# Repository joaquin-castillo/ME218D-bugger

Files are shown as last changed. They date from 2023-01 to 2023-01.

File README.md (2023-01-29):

# ME218D-bugger
Design files and documentation for the ME 218 D-bugger. The D-bugger is a tool for ME 218 student students to monitor and visualize the Events and Services Framework.

## PCBA fabrication and assembly
### Fab House
We had [JLCPCB](https://jlcpcb.com/) fabricate the boards and assemble the bottom sides. We elected to solder the top sides ourselves because, in addition to the three thru-hole components, there are only four 1206 SMD components on the top sides, and having both sides assembled with have cost significantly more. 1206 SMD packages are not difficult to solder by hand with the right equipment. If you are new to SMD soldering, see this [Intro to Soldering](https://sites.google.com/stanford.edu/soldering-internal/learning?authuser=0) tutorial page to learn the basics and best practices of hand soldering. A lesson we learned was to avoid no-clean solder flux and opt for water-soluble solder flux instead. This can be cleaned with isopropyl alcohol (at least 90%) or water and will not leave the board sticky and goopy after soldering.

The fabrication files needed to place an order with JLC are listed below:
- *Intermediary_revC_fab_20221219.zip*
- *Intermediary_revC_jlc_bottom.csv*
- *Intermediary_revC_4layer-bottom-pos.csv*

If for any reason you need to regenerate the fab files, JLC has some tutorials on [How to generate Gerber and Drill files](https://support.jlcpcb.com/article/194-how-to-generate-gerber-and-drill-files-in-kicad-6) and [How to generate the BOM and Centroid file](https://support.jlcpcb.com/article/84-how-to-generate-the-bom-and-centroid-file-from-kicad) specifically for KiCAD. The BOM and centroid file (aka pick and place file) are used for component assembly. In our experience, getting the centroid file in the right position and orientation relative to the board preview in JLC's quoting tool was a little finicky. This doesn't have to be perfect as JLC will have an engineer look at your files and correct anything before you approve the order. Something else to note is that for assembly, JLC requires some non-plated tooling hole to be added to the board for their processes. These have already been added to the design, but in case you want to see their requirements, that can be found on this page: [How to add tooling holes for PCB assembly order](https://support.jlcpcb.com/article/92-how-to-add-tooling-holes-for-smt-assembly-order).

### In House
Upon receiving the board from the fab house, they will still require a few components to be hand soldered. This includes:
- DIP-28 Socket (for the PIC)
- 3-pin header
- USB C receptacle
- 1206 SMD Green LED
- 1206 SMD Blue LEDs x2
- 1206 SMD 620 Ohm resistor

These can be found in the *Intermediary_revC_BOM.xlsx* file with links for DigiKey. The image below shows all seven components to be hand soldered:

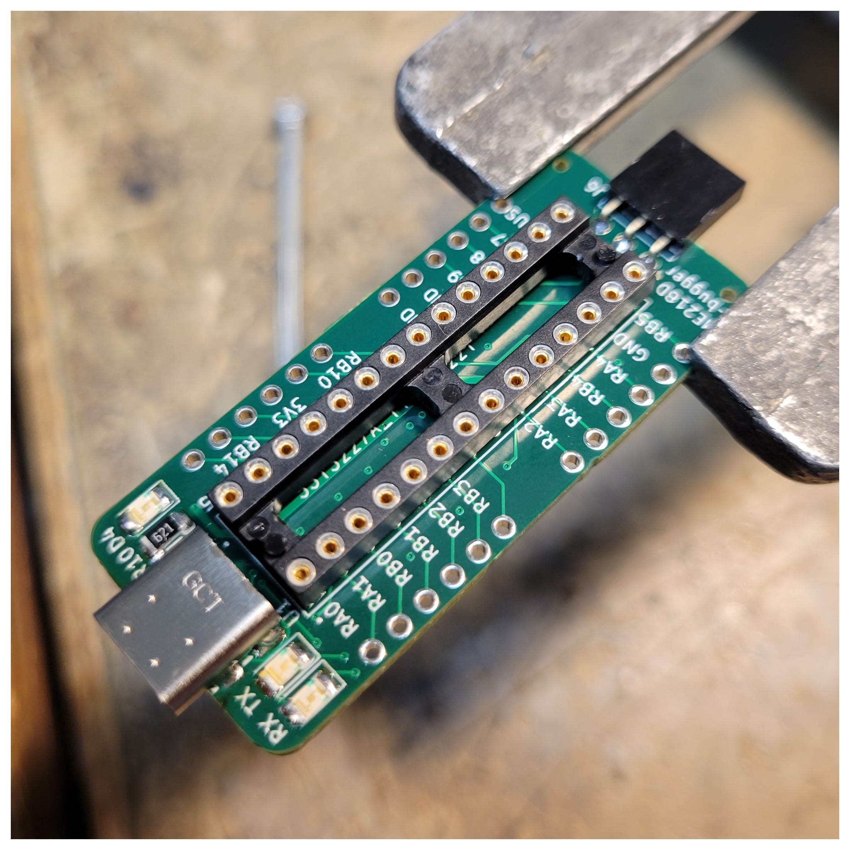
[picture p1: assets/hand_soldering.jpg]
hand_soldering


Additionally, the boards must be configured at assembly to work with either the CP2102N serial bridge, or the PIC32's native USB. To do this, simply create solder bridges on the three jumper pads on the back side of the board as shown below:

solder_jumpers

To reconfigure the boards in the future, simply wick away the solder bridges and resolder the opposite pads.

## Enclosure

## Firmware
### PIC32 Microcontroller
The PIC needs to be programmed with the latest version of the D-bugger firmware. The latest firmware can be found [here]. Using a breadboard or ZIF socket, program the PIC with the SNAP programmer through MPLAB.

### CP2102N Serial Bridge
Though the serial bridge will work out-of-the-box, it should be configured to enable the RX and TX toggle LEDs, which are disabled by default. These LEDs are helpful for troublshooting communications issues from the target or to the host.

To do this, you must download Silicon Labs [Simplicity Studio](https://www.silabs.com/developers/simplicity-studio) and install it on your computer. You may be asked to create an account. Once installed, plug the D-bugger into your computer before opening the application. Once open, you shoud see the following window. If not, close or cancel out of any pop-up windows that may have appeared.

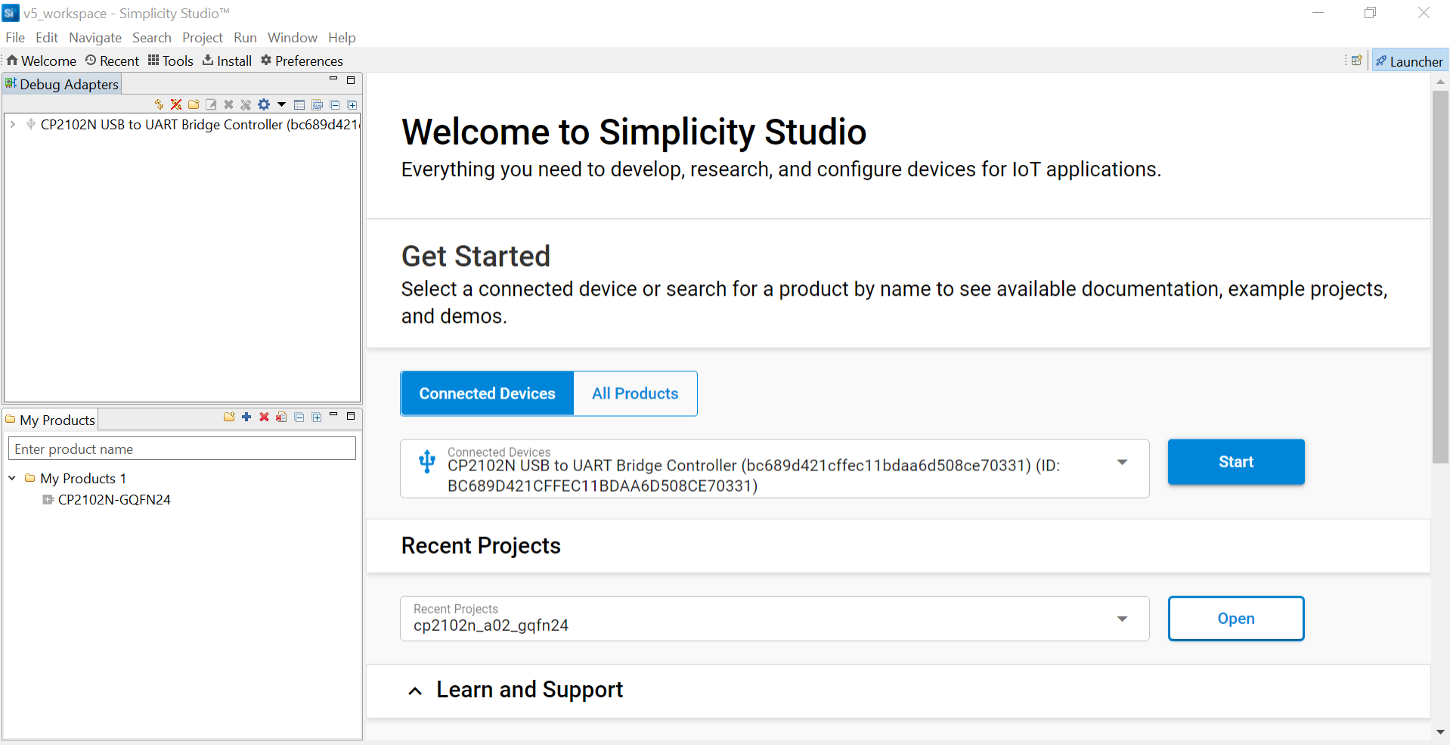
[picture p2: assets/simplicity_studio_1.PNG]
simplicity_studio_1


The CP2102N serial bridge should appear under **Connected Devices**. Click on **Start** to continue to the next screen.

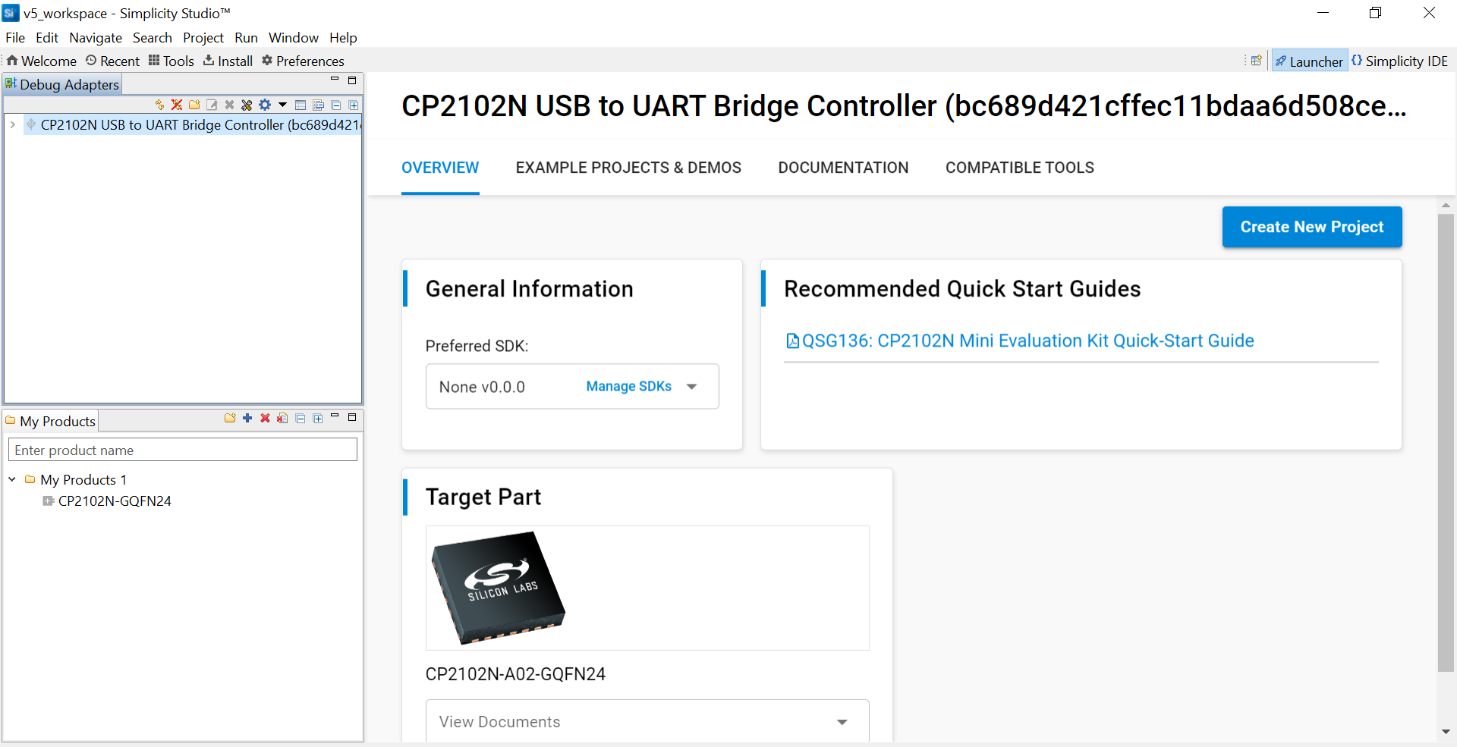
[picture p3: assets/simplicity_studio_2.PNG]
simplicity_studio_2


Next, click on **Create New Project**.

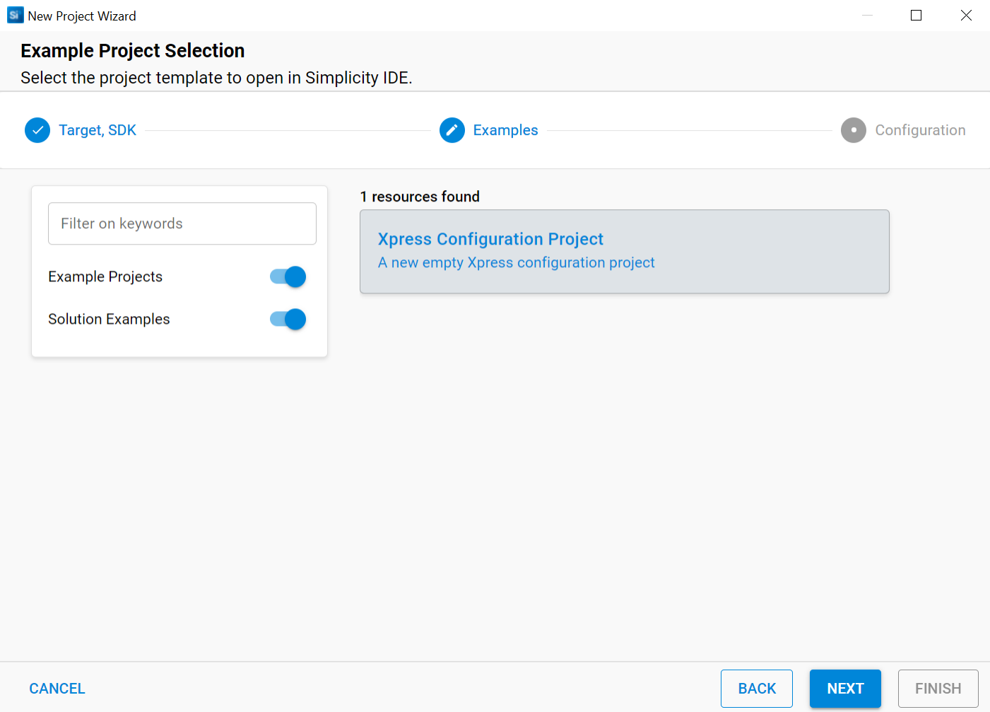
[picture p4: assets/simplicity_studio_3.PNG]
simplicity_studio_3


The example project selected should be the **Xpress Configuration Project**. Click on **Next** to continue.

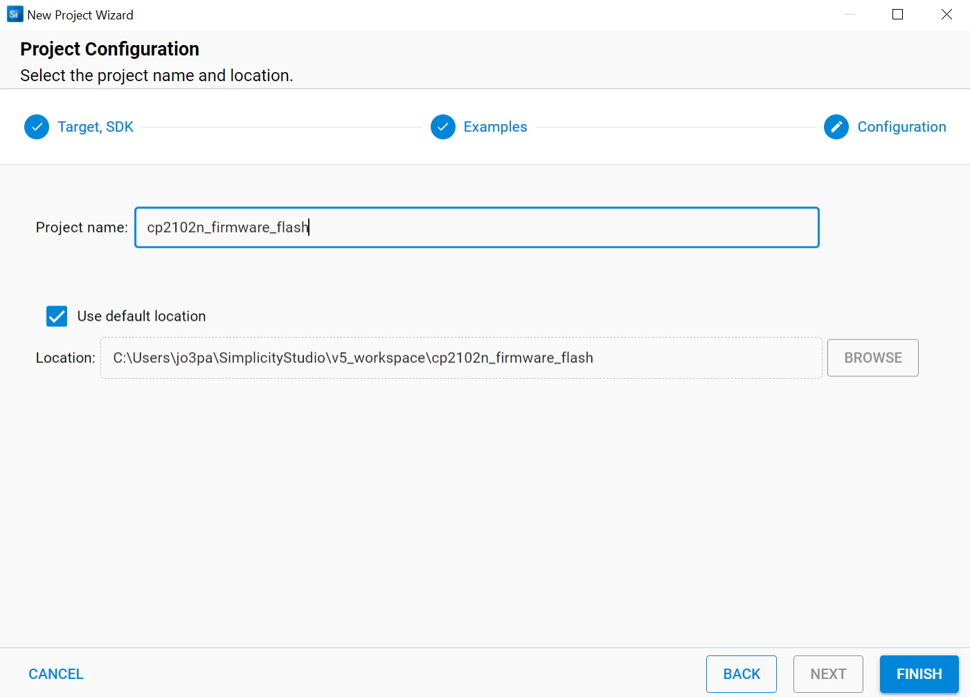
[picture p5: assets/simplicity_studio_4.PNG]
simplicity_studio_4


Here you can rename the project and choose where it will be saved. Once you're done, click on **Finish**.

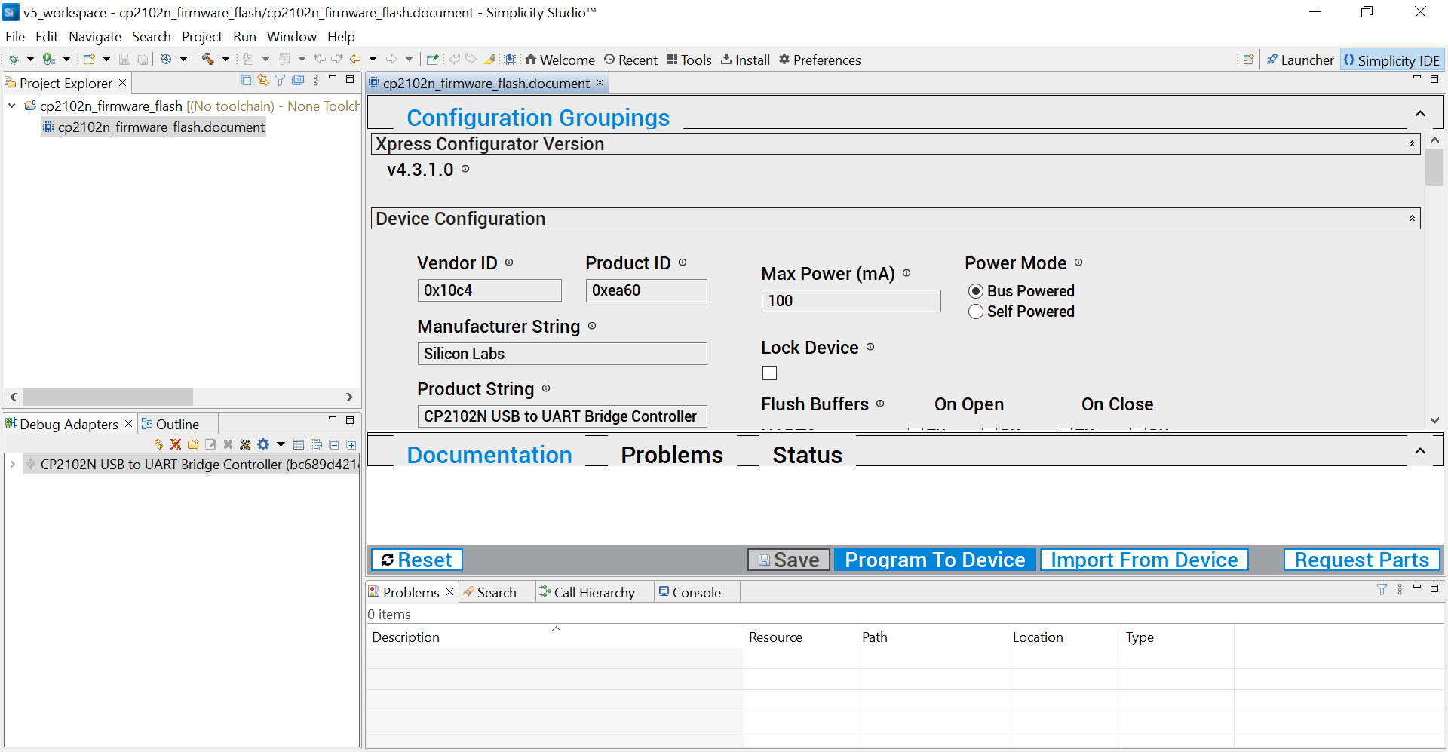
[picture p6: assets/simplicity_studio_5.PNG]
simplicity_studio_5


You are now able to configure the chip's firmware. To enable the RX and TX toggle LEDs, scroll down to **Port Configuration: GPIO**. Be careful not to scroll with your cusor over a dropdown menu as the menu can cycle through its options and set some undesired configuration.

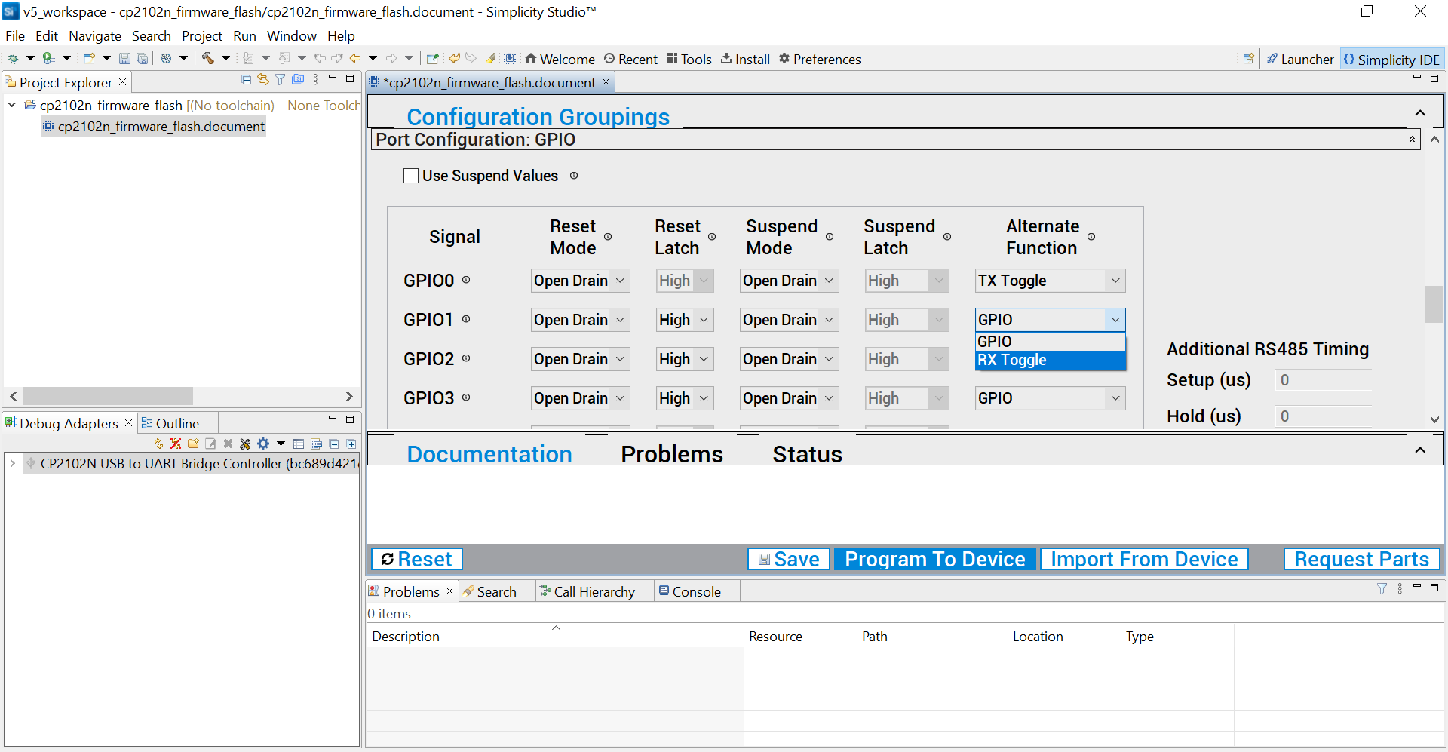
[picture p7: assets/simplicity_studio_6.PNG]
simplicity_studio_6


Under **Alternate Function**, for **GPIO0** and **GPIO1** select **TX Toggle** and **RX Toggle** from their respective dropdown menus. No other reconfigurations are necessary for the D-bugger. Click on **Save** and **Program To Device** to reprogram the chip.

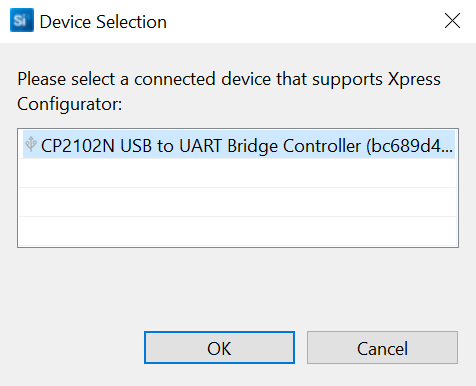
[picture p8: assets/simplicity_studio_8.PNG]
simplicity_studio_8


In the pop-up window, ensure the CP2102N chip is selected and click on **OK**.

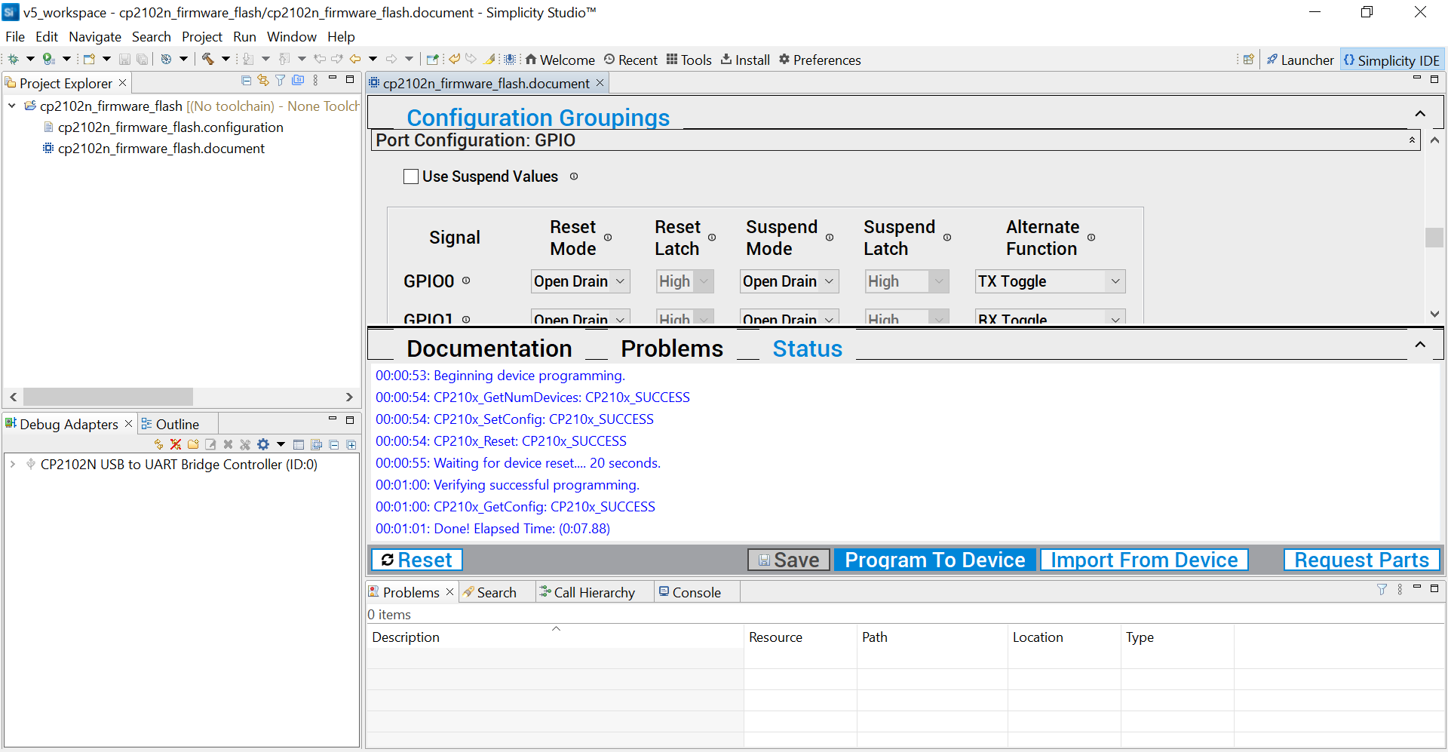
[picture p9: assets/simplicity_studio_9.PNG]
simplicity_studio_9


To confirm that the device has been successfully programed, you will see the following message in the **Status** window. You are now done and may now close out of the application!

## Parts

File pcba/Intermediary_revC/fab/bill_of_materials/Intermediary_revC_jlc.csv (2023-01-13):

Comment | Designator | Footprint | LCSC Part Number
0.1uF | C1, C2, C4, C5, C8, C9, | C_1206_3216Metric | C541547
4.7uF | C3, C7, C10, | C_1206_3216Metric | C132148
10uF | C6, | C_1206_3216Metric | C128855
BLUE LED | D1, D3, | LED_1206_3216Metric | C131245
SP0503BAHT | D2, | Package_TO_SOT_SMD:SOT-143 | C7074
GREEN LED | D4, | LED_1206_3216Metric | C73550
CP2102N-A02-GQFN24 | IC1, | QFN50P400X400X80-25N | C969151
1K Ohm | R1, R3, | R_1206_3216Metric | C131398
10K Ohm | R2, | R_1206_3216Metric | C132649
22K Ohm | R4, | R_1206_3216Metric | C114942
47K Ohm | R5, | R_1206_3216Metric | C136469
5.1K Ohm | R6, R7, | R_1206_3216Metric | C163372
620 Ohm | R8, R9, R10, | R_1206_3216Metric | C185260
DIP 28 Socket | U1, | OST_ED281DT | C2874014

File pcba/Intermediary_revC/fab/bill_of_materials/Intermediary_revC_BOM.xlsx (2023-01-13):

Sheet: parts list
PN | Description | Qty | Symbols | Link
PIC32MX250F128B-50I/SP | micro | 1 | U1 | https://www.digikey.com/en/products/detail/microchip-technology/PIC32MX270F256B-50I-SP/4902626
SA283040 | micro socket | 1 | U1 | https://www.digikey.com/en/products/detail/on-shore-technology-inc/SA283040/3313539
CP2102N-A02-GQFN24 | serial bridge | 1 | IC1 | https://www.digikey.com/en/products/detail/silicon-labs/CP2102N-A02-GQFN24R/9863479
CC1206JRX7R9BB104 | 0.1uF cap | 6 | C1,2,4,5,8,9 | https://www.digikey.com/en/products/detail/yageo/CC1206JRX7R9BB104/2833600
C1206C475J8NAC7800 | 4.7uF cap | 3 | C3,7,10 | https://www.digikey.com/en/products/detail/kemet/C1206C475J8NAC7800/2236756
C1206C106J8RAC7800 | 10uF cap | 1 | C6 | https://www.digikey.com/en/products/detail/kemet/C1206C106J8RAC7800/2215112
CRCW1206620RJNEAHP | 620 res | 3 | R8,9,10 | https://www.digikey.com/en/products/detail/vishay-dale/CRCW1206620RJNEAHP/2228139
RC1206JR-7W1KL | 1K res | 4 | R1,3,8,9 | https://www.digikey.com/en/products/detail/yageo/RC1206JR-7W1KL/12698814
RCS12065K10JNEA | 5.1K res | 2 | R6,7 | https://www.digikey.com/en/products/detail/vishay-dale/RCS12065K10JNEA/10059733
CRM1206-JW-103ELF | 10K res | 1 | R2 | https://www.digikey.com/en/products/detail/bourns-inc/CRM1206-JW-103ELF/4698313
ERJ-P08J223V | 22K res | 1 | R4 | https://www.digikey.com/en/products/detail/panasonic-electronic-components/ERJ-P08J223V/525359
ESR18EZPJ473 | 47K res | 1 | R5 | https://www.digikey.com/en/products/detail/rohm-semiconductor/ESR18EZPJ473/1762909
APT3216LVBC/D | blue led | 2 | D1,3 | https://www.digikey.com/en/products/detail/kingbright/APT3216LVBC-D/5177444
APT3216LZGCK | green led | 1 | D4 | https://www.digikey.com/en/products/detail/kingbright/APT3216LZGCK/5177445
SP0503BAHTG | protect diodes | 1 | D2 | https://www.digikey.com/en/products/detail/littelfuse-inc/SP0503BAHTG/1154308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
PPPC031LGBN-RC | 1x3 socket h | 1 | J6 | https://www.digikey.com/en/products/detail/sullins-connector-solutions/PPPC031LGBN-RC/775936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
PPPC061LFBN-RC | 1x6 socket v | 4 | J1,2,3,4 | https://www.digikey.com/en/products/detail/sullins-connector-solutions/PPPC061LFBN-RC/810178
USB4085-GF-A | usb c | 1 | J5 | https://www.digikey.com/en/products/detail/gct/USB4085-GF-A/9859662
PLPC2-250 | light pipe | 3 | n/a | https://www.digikey.com/en/products/detail/bivar-inc/PLPC2-250/5721860?s=N4IgTCBcDaIAoBk4GEwFowFYAMIC6AvkA

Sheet: parts list (top)
PN | Description | Qty | Symbols | Link
PIC32MX250F128B-50I/SP | micro | 1 | U1 | https://www.digikey.com/en/products/detail/microchip-technology/PIC32MX270F256B-50I-SP/4902626
SA283040 | micro socket | 1 | U1 | https://www.digikey.com/en/products/detail/on-shore-technology-inc/SA283040/3313539
CRCW1206620RJNEAHP | 620 res | 1 | R10 | https://www.digikey.com/en/products/detail/vishay-dale/CRCW1206620RJNEAHP/2228139
APT3216LVBC/D | blue led | 2 | D1,3 | https://www.digikey.com/en/products/detail/kingbright/APT3216LVBC-D/5177444
APT3216LZGCK | green led | 1 | D4 | https://www.digikey.com/en/products/detail/kingbright/APT3216LZGCK/5177445
PPPC031LGBN-RC | 1x3 socket h | 1 | J6 | https://www.digikey.com/en/products/detail/sullins-connector-solutions/PPPC031LGBN-RC/775936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
PPPC061LFBN-RC | 1x6 socket v | 4 | J1,2,3,4 | https://www.digikey.com/en/products/detail/sullins-connector-solutions/PPPC061LFBN-RC/810178
USB4085-GF-A | usb c | 1 | J5 | https://www.digikey.com/en/products/detail/gct/USB4085-GF-A/9859662
PLPC2-250 | light pipe | 3 | n/a | https://www.digikey.com/en/products/detail/bivar-inc/PLPC2-250/5721860?s=N4IgTCBcDaIAoBk4GEwFowFYAMIC6AvkA

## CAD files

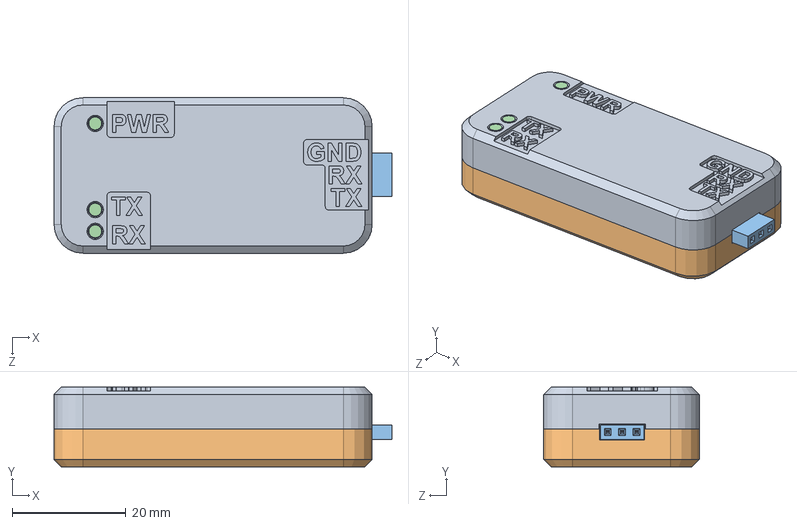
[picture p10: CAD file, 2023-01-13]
enclosure/intermediary_enclosure_assy.SLDASM
59.4 x 14.0 x 27.3 mm
Intermediary_revB
intermediary_enclosure_bottom
intermediary_enclosure_top
light_pipe x 3

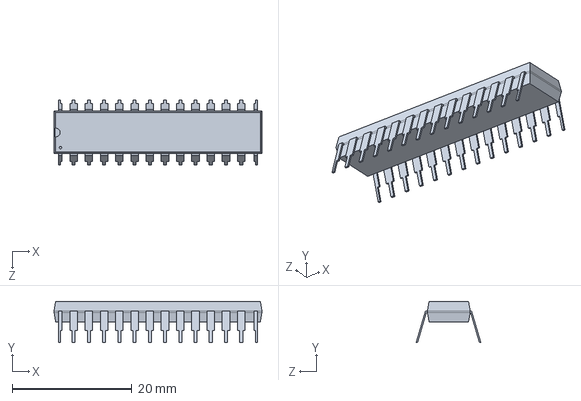
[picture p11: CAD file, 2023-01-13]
pcba/Intermediary_revC/3D_files/PIC32MX270F256B-50I_SP.SLDASM
34.7 x 6.91 x 10.8 mm

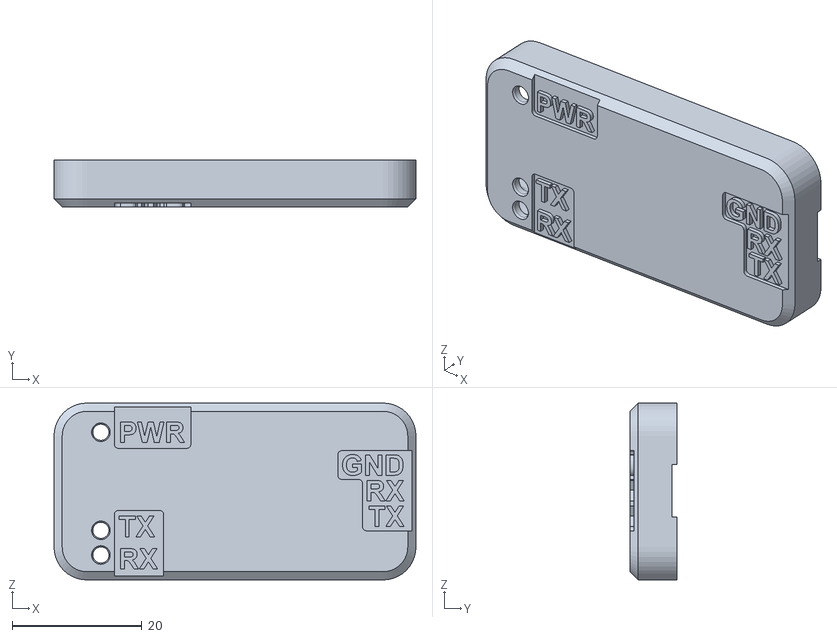
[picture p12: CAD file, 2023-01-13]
enclosure/fab/intermediary_enclosure_top.STL
55.9 x 7.31 x 27.3

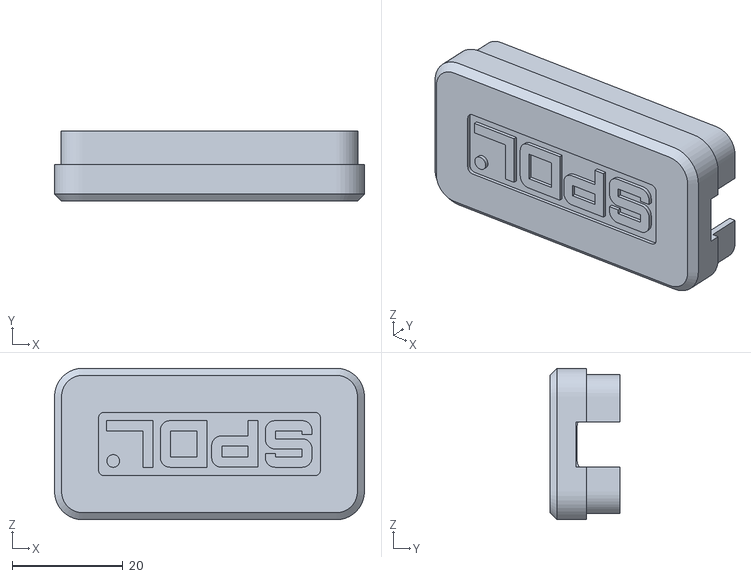
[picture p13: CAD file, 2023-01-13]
enclosure/fab/intermediary_enclosure_bottom.STL
55.9 x 12.7 x 27.3

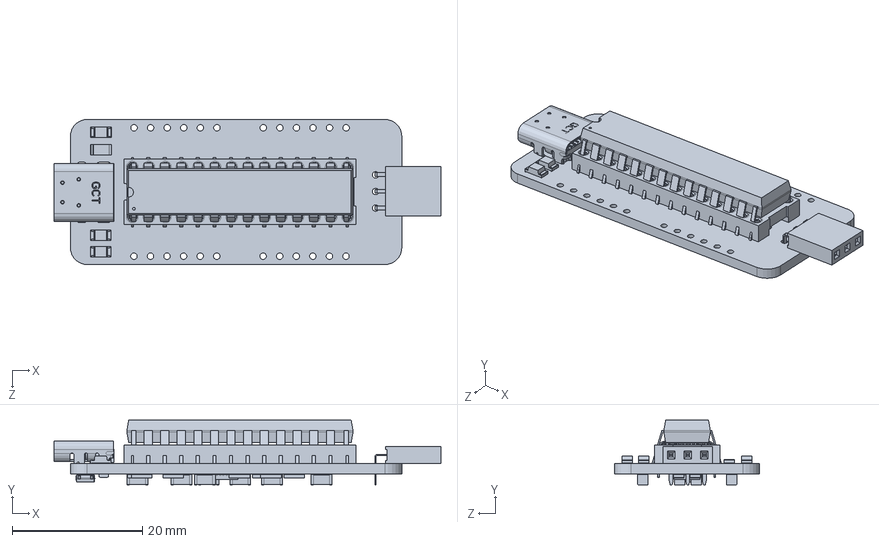
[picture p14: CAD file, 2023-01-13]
enclosure/Intermediary_revB.SLDPRT
59.3 x 9.90 x 22.2 mm

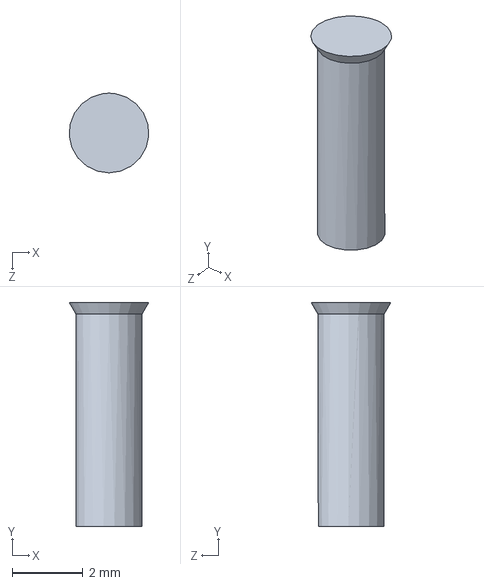
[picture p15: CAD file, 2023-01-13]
enclosure/light_pipe.SLDPRT
2.25 x 6.35 x 2.26 mm

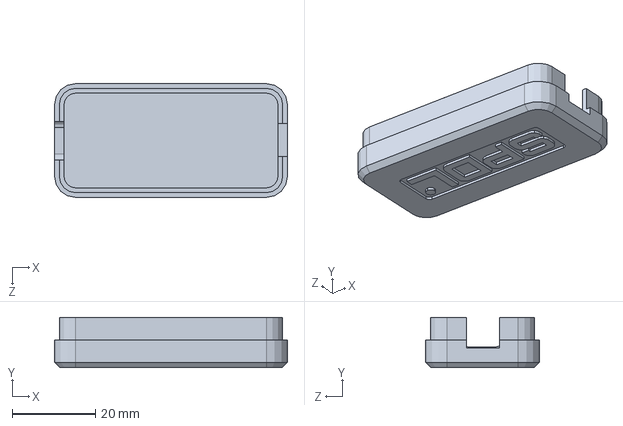
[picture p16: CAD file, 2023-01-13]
enclosure/intermediary_enclosure_bottom.SLDPRT
55.9 x 12.1 x 27.3 mm

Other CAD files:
pcba/Intermediary_revC/3D_files/LED_1206_3216Metric.SLDASM
pcba/Intermediary_revC/3D_files/R_1206_3216Metric.SLDASM
pcba/Intermediary_revC/3D_files/PinSocket_1x03_P2.54mm_Horizontal.SLDASM
pcba/Intermediary_revC/3D_files/C_1206_3216Metric.SLDASM
pcba/Intermediary_revC/3D_files/SOT-143.SLDASM
pcba/Intermediary_revC/3D_files/CP2102N-A02-GQFN24.SLDASM
pcba/Intermediary_revC/3D_files/114-87-328-41-134161.SLDASM
enclosure/intermediary_enclosure_top.SLDPRT
pcba/Intermediary_revC/3D_files/SOLID_5.SLDPRT
pcba/Intermediary_revC/3D_files/SOLID.SLDPRT
pcba/Intermediary_revC/3D_files/SOLID_6.SLDPRT
pcba/Intermediary_revC/3D_files/COMPOUND_2.SLDPRT
pcba/Intermediary_revC/3D_files/SOLID_2.SLDPRT
pcba/Intermediary_revC/3D_files/SOLID_3.SLDPRT
pcba/Intermediary_revC/3D_files/SOLID_4.SLDPRT
pcba/Intermediary_revC/3D_files/SOLID_7.SLDPRT

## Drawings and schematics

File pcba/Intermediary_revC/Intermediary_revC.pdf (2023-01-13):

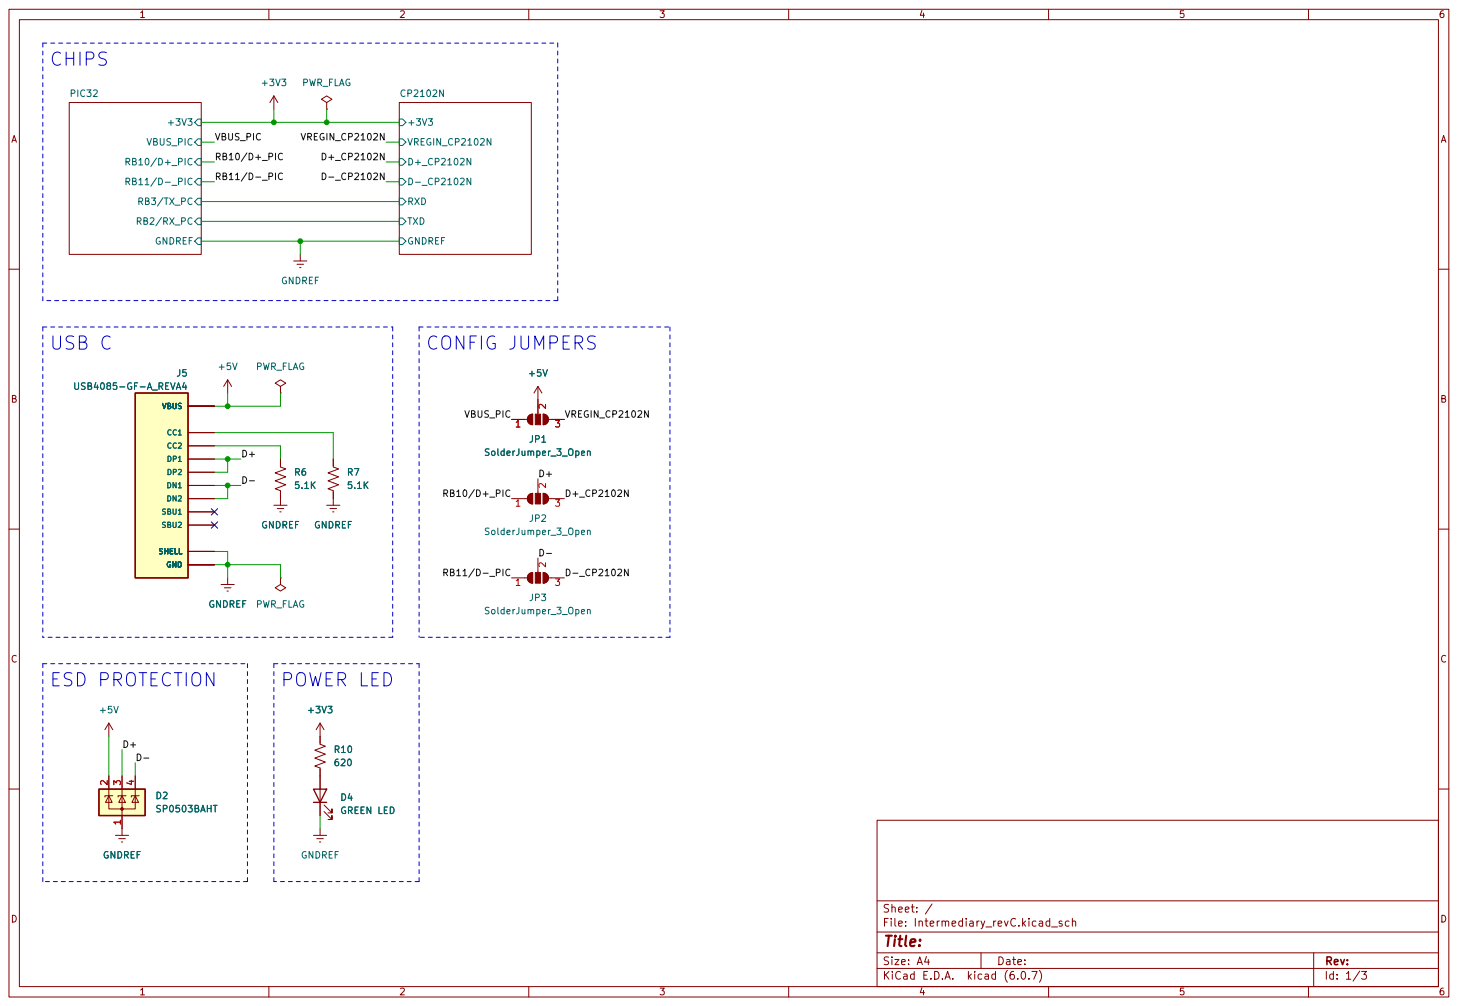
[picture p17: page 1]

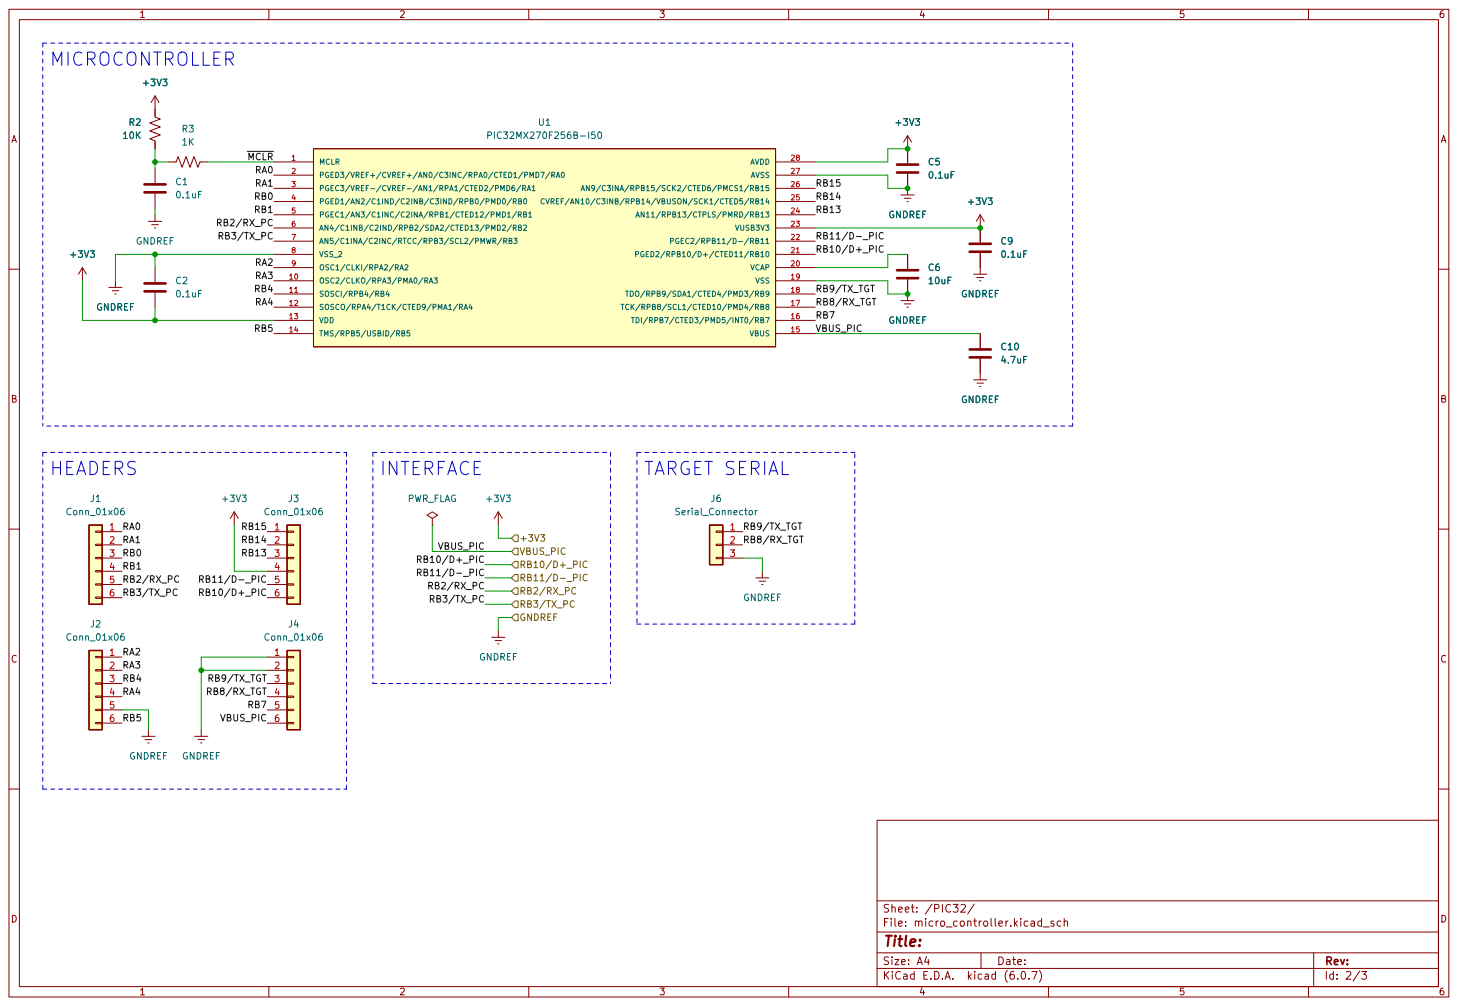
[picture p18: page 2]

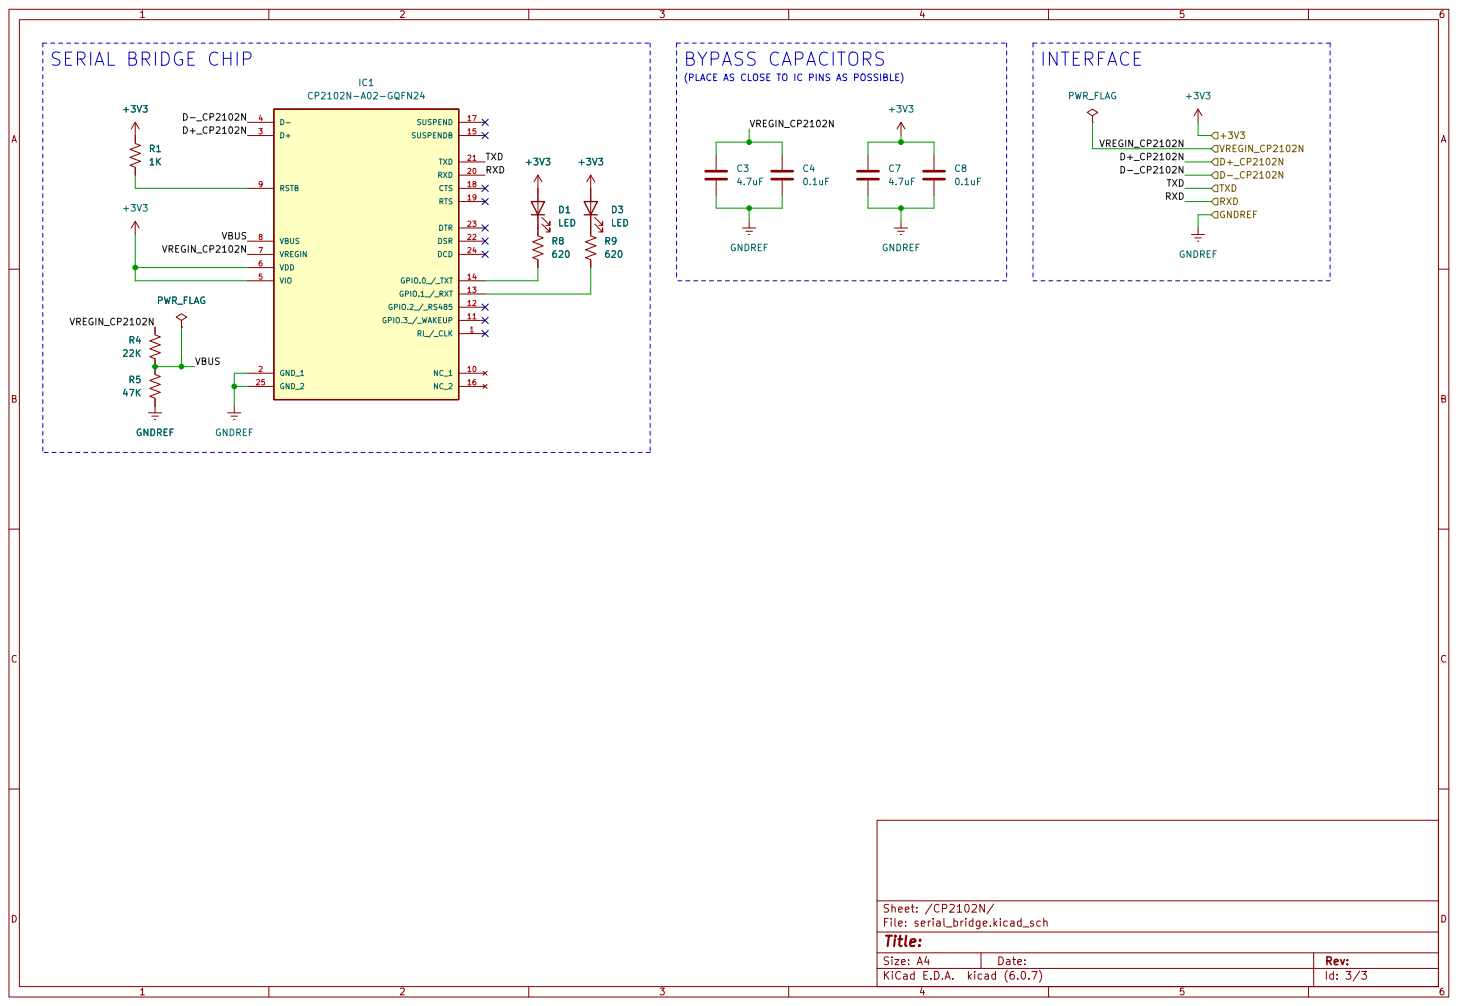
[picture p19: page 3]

(PLACE AS CLOSE TO IC PINS AS POSSIBLE)

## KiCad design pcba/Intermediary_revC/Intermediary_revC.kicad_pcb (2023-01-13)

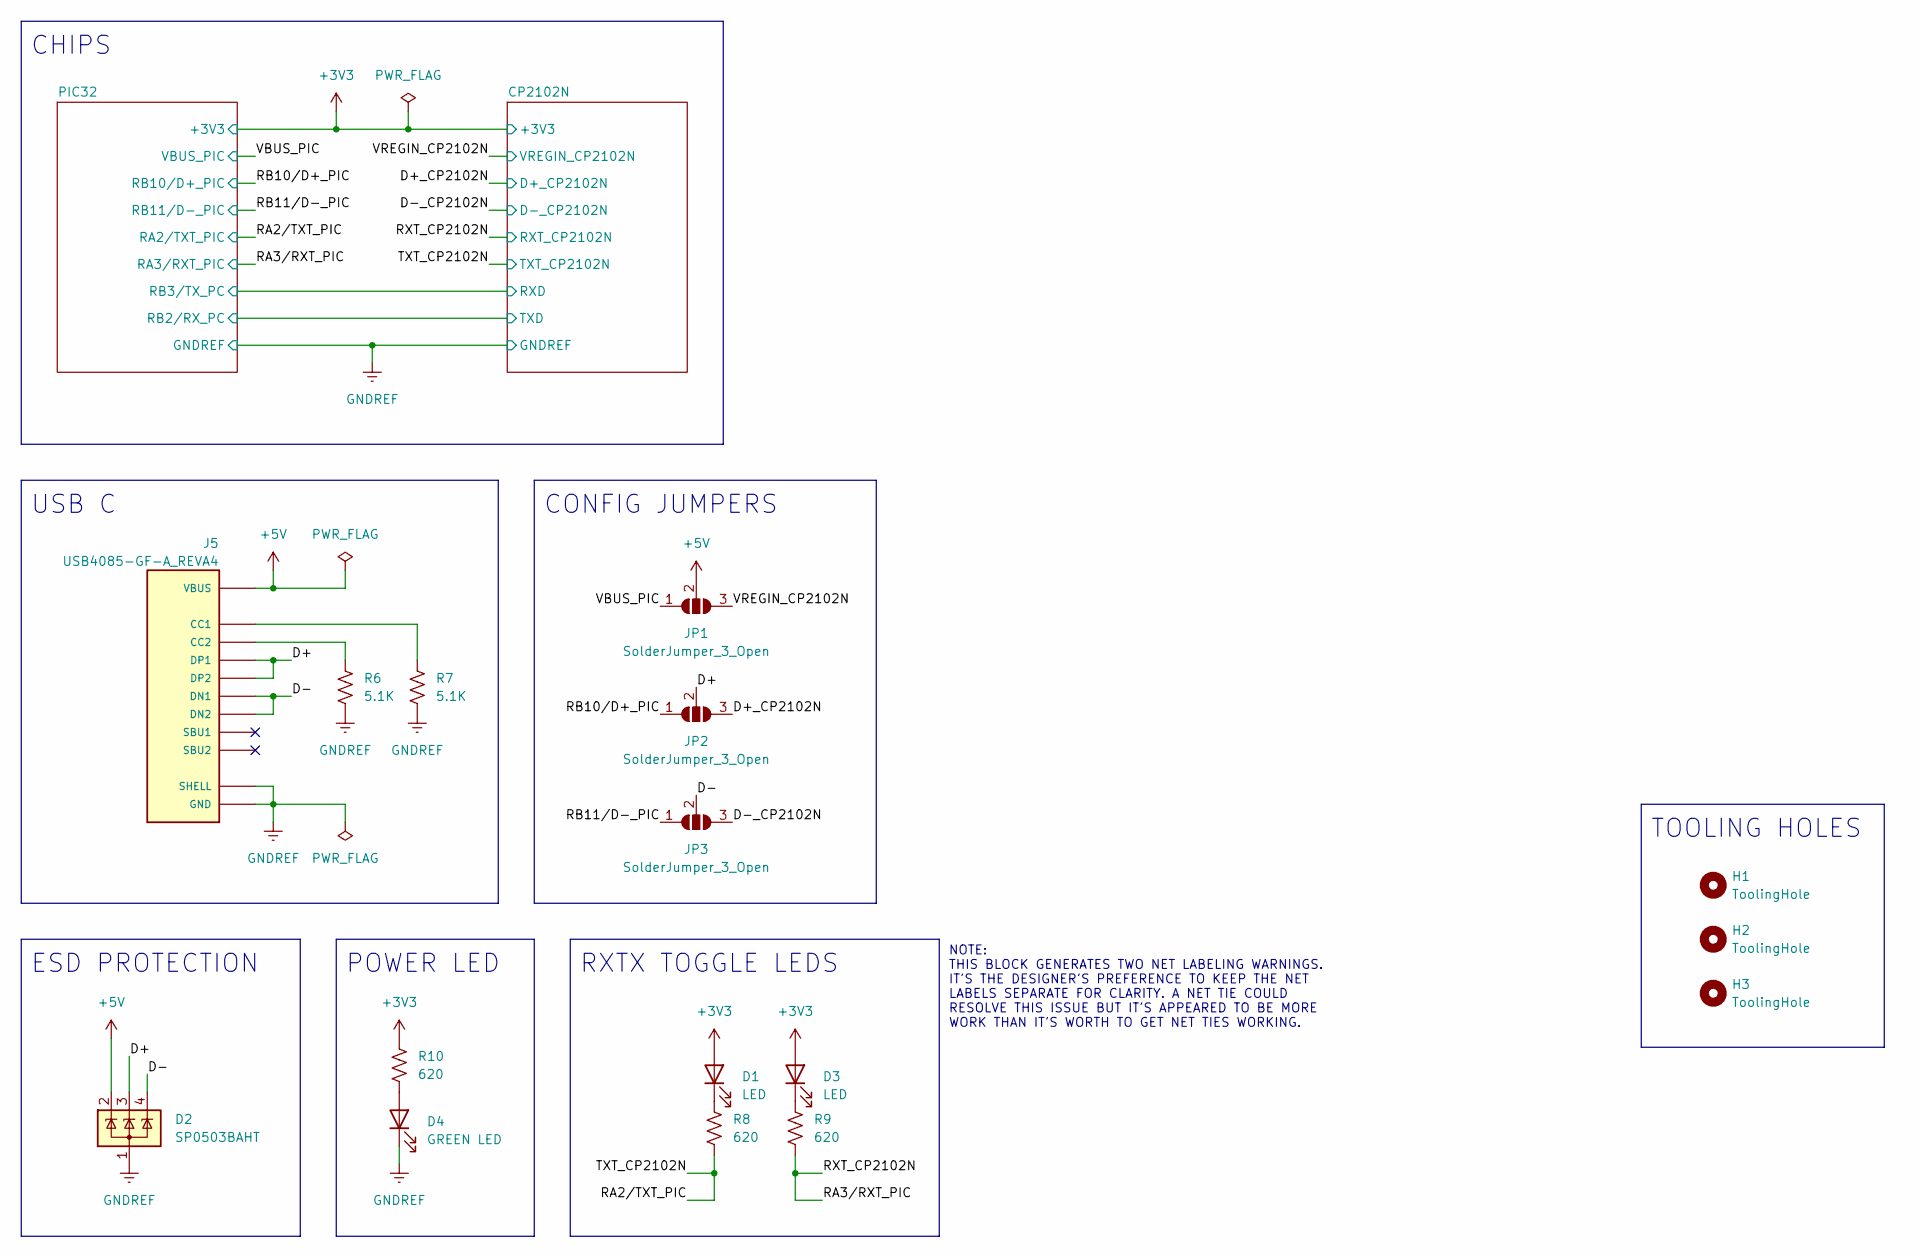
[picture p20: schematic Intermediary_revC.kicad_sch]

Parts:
D1, D3: LED; LED_1206_3216Metric
D2: SP0503BAHT; SOT-143
D4: GREEN LED; LED_1206_3216Metric
H1, H2, H3: ToolingHole; JLCPCB_Tooling_Hole
J5: USB4085-GF-A_REVA4; GCT_USB4085-GF-A_REVA4; PARTREV A4
JP1, JP2, JP3: SolderJumper_3_Open; SolderJumper-3_P2.0mm_Open_TrianglePad1.0x1.5mm_NumberLabels
R6, R7: 5.1K; R_1206_3216Metric
R8, R9, R10: 620; R_1206_3216Metric

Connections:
+3V3: D1.2 (A), D3.2 (A), R10.1; also elsewhere on the board
+5V: D2.2 (K), J5.A4 (VBUS), J5.A9 (VBUS), J5.B4 (VBUS), J5.B9 (VBUS), JP1.2 (C)
/D+: D2.3 (K), J5.A6 (DP1), J5.B6 (DP2), JP2.2 (C)
/D+_CP2102N: JP2.3 (B); also elsewhere on the board
/D-: D2.4 (K), J5.A7 (DN1), J5.B7 (DN2), JP3.2 (C)
/D-_CP2102N: JP3.3 (B); also elsewhere on the board
/RA2/TXT_PIC: R8.2; also elsewhere on the board
/RA3/RXT_PIC: R9.2; also elsewhere on the board
/RB10/D+_PIC: JP2.1 (A); also elsewhere on the board
/RB11/D-_PIC: JP3.1 (A); also elsewhere on the board
/VBUS_PIC: JP1.1 (A); also elsewhere on the board
/VREGIN_CP2102N: JP1.3 (B); also elsewhere on the board
GNDREF: D2.1 (A), D4.1 (K), J5.A1 (GND), J5.A12 (GND), J5.B1 (GND), J5.B12 (GND), J5.S1 (SHELL), J5.S2 (SHELL), J5.S3 (SHELL), J5.S4 (SHELL), R6.2, R7.2; also elsewhere on the board
unnamed: D1.1 (K), R8.1
unnamed: D3.1 (K), R9.1
unnamed: D4.2 (A), R10.2
unnamed: J5.A5 (CC1), R7.1
unnamed: J5.B5 (CC2), R6.1

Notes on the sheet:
ESD PROTECTION
USB C
CONFIG JUMPERS
POWER LED
NOTE: THIS BLOCK GENERATES TWO NET LABELING WARNINGS. IT'S THE DESIGNER'S PREFERENCE TO KEEP THE NET LABELS SEPARATE FOR CLARITY. A NET TIE COULD RESOLVE THIS ISSUE BUT IT'S APPEARED TO BE MORE WORK THAN IT'S WORTH TO GET NET TIES WORKING.
CHIPS
TOOLING HOLES
RXTX TOGGLE LEDS

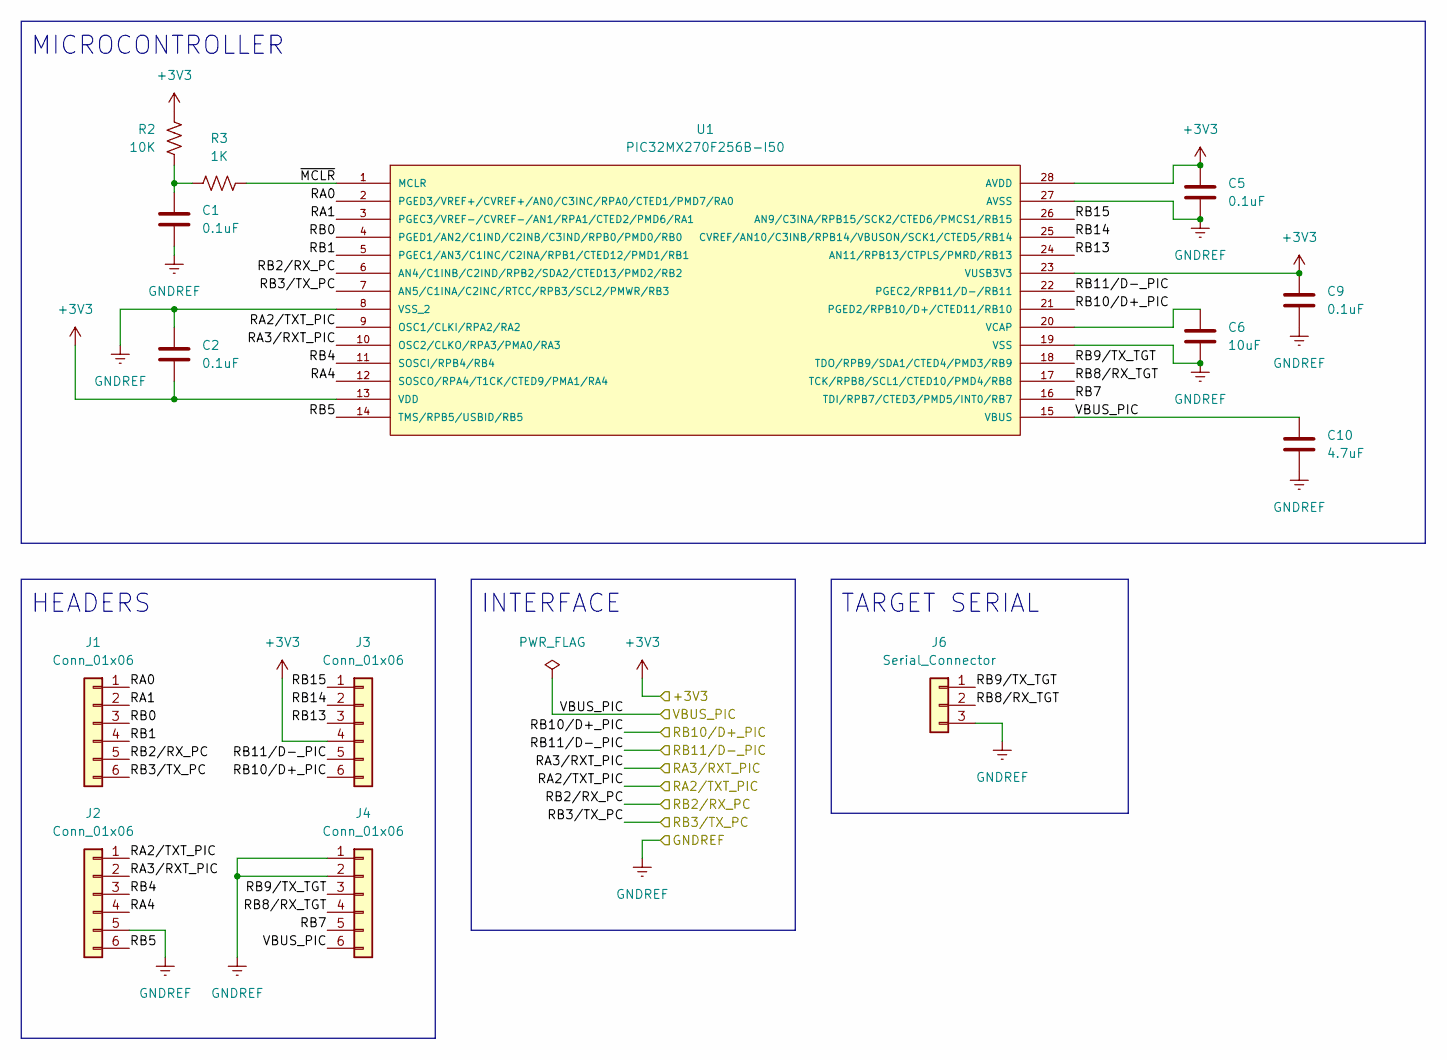
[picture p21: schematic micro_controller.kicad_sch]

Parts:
C1, C2, C5, C9: 0.1uF; C_1206_3216Metric
C6: 10uF; C_1206_3216Metric
C10: 4.7uF; C_1206_3216Metric
J1, J2, J3, J4: Conn_01x06; PinSocket_1x06_P2.54mm_Vertical
J6: Serial_Connector; PinSocket_1x03_P2.54mm_Horizontal
R2: 10K; R_1206_3216Metric
R3: 1K; R_1206_3216Metric
U1: PIC32MX270F256B-I50; OST_ED281DT

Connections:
+3V3: C2.2, C5.1, C9.1, J3.4, R2.1, U1.13 (VDD), U1.23 (VUSB3V3), U1.28 (AVDD); also elsewhere on the board
/CP2102N/RXD: J1.6, U1.7 (AN5/C1INA/C2INC/RTCC/RPB3/SCL2/PMWR/RB3); also elsewhere on the board
/CP2102N/TXD: J1.5, U1.6 (AN4/C1INB/C2IND/RPB2/SDA2/CTED13/PMD2/R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); also elsewhere on the board
/PIC32/RA0: J1.1, U1.2 (PGED3/VREF+/CVREF+/AN0/C3INC/RPA0/CTED1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)
/PIC32/RA1: J1.2, U1.3 (PGEC3/VREF-/CVREF-/AN1/RPA1/CTED2/PMD6/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)
/PIC32/RA4: J2.4, U1.12 (SOSCO/RPA4/T1CK/CTED9/PMA1/RA4)
/PIC32/RB0: J1.3, U1.4 (PGED1/AN2/C1IND/C2INB/C3IND/RPB0/PMD0/R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)
/PIC32/RB1: J1.4, U1.5 (PGEC1/AN3/C1INC/C2INA/RPB1/CTED12/PMD1/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)
/PIC32/RB4: J2.3, U1.11 (SOSCI/RPB4/RB4)
/PIC32/RB5: J2.6, U1.14 (TMS/RPB5/USBID/RB5)
/PIC32/RB7: J4.5, U1.16 (TDI/RPB7/CTED3/PMD5/INT0/RB7)
/PIC32/RB8/RX_TGT: J4.4, J6.2, U1.17 (TCK/RPB8/SCL1/CTED10/PMD4/RB8)
/PIC32/RB9/TX_TGT: J4.3, J6.1, U1.18 (TDO/RPB9/SDA1/CTED4/PMD3/RB9)
/PIC32/RB13: J3.3, U1.24 (AN11/RPB13/CTPLS/PMRD/RB13)
/PIC32/RB14: J3.2, U1.25 (CVREF/AN10/C3INB/RPB14/VBUSON/SCK1/CTED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)
/PIC32/RB15: J3.1, U1.26 (AN9/C3INA/RPB15/SCK2/CTED6/PMCS1/RB15)
/PIC32/~MCLR: R3.2, U1.1 (MCLR)
/RA2/TXT_PIC: J2.1, U1.9 (OSC1/CLKI/RPA2/RA2); also elsewhere on the board
/RA3/RXT_PIC: J2.2, U1.10 (OSC2/CLKO/RPA3/PMA0/RA3); also elsewhere on the board
/RB10/D+_PIC: J3.6, U1.21 (PGED2/RPB10/D+/CTED11/RB10); also elsewhere on the board
/RB11/D-_PIC: J3.5, U1.22 (PGEC2/RPB11/D-/RB11); also elsewhere on the board
/VBUS_PIC: C10.1, J4.6, U1.15 (VBUS); also elsewhere on the board
GNDREF: C1.2, C2.1, C5.2, C6.2, C9.2, C10.2, J2.5, J4.1, J4.2, J6.3, U1.8 (VSS_2), U1.19 (VSS), U1.27 (AVSS); also elsewhere on the board
unnamed: C1.1, R2.2, R3.1
unnamed: C6.1, U1.20 (VCAP)

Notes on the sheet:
INTERFACE
TARGET SERIAL
HEADERS
MICROCONTROLLER

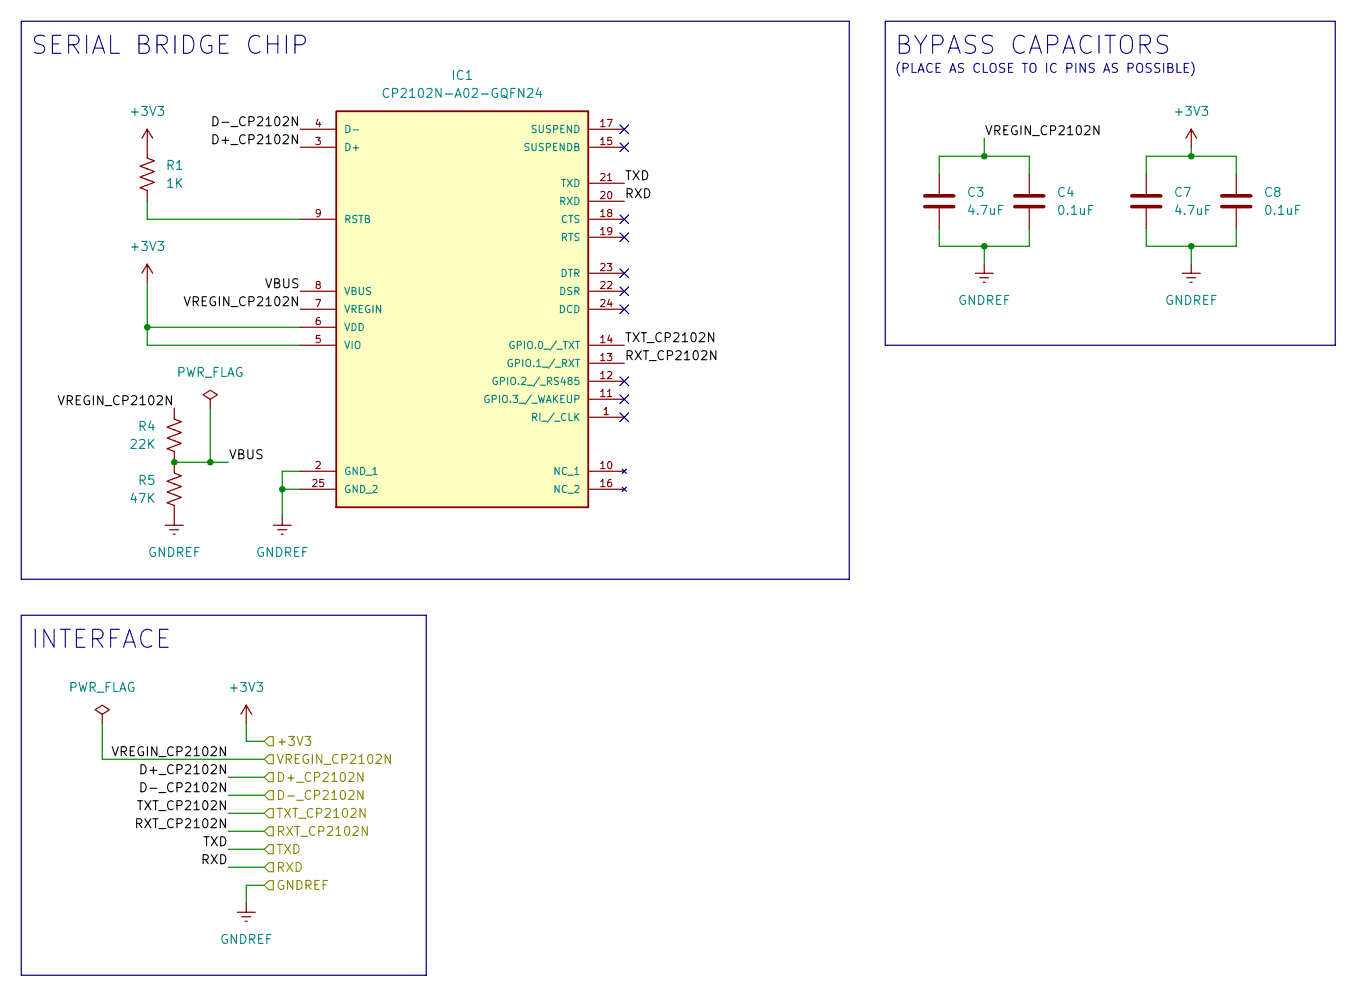
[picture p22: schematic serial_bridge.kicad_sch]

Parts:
C3, C7: 4.7uF; C_1206_3216Metric
C4, C8: 0.1uF; C_1206_3216Metric
IC1: CP2102N-A02-GQFN24; QFN50P400X400X80-25N; MOUSER_PART_NUMBER 634-CP2102NA02GQFN24
R1: 1K; R_1206_3216Metric
R4: 22K; R_1206_3216Metric
R5: 47K; R_1206_3216Metric

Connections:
+3V3: C7.1, C8.1, IC1.5 (VIO), IC1.6 (VDD), R1.1; also elsewhere on the board
/CP2102N/RXD: IC1.20 (RXD); also elsewhere on the board
/CP2102N/TXD: IC1.21 (TXD); also elsewhere on the board
/CP2102N/VBUS: IC1.8 (VBUS), R4.2, R5.1
/D+_CP2102N: IC1.3 (D+); also elsewhere on the board
/D-_CP2102N: IC1.4 (D-); also elsewhere on the board
/RA2/TXT_PIC: IC1.14 (GPIO.0_/_TXT); also elsewhere on the board
/RA3/RXT_PIC: IC1.13 (GPIO.1_/_RXT); also elsewhere on the board
/VREGIN_CP2102N: C3.1, C4.1, IC1.7 (VREGIN), R4.1; also elsewhere on the board
GNDREF: C3.2, C4.2, C7.2, C8.2, IC1.2 (GND_1), IC1.25 (GND_2), R5.2; also elsewhere on the board
unnamed: IC1.9 (RSTB), R1.2

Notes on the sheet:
INTERFACE
BYPASS CAPACITORS
SERIAL BRIDGE CHIP
(PLACE AS CLOSE TO IC PINS AS POSSIBLE)

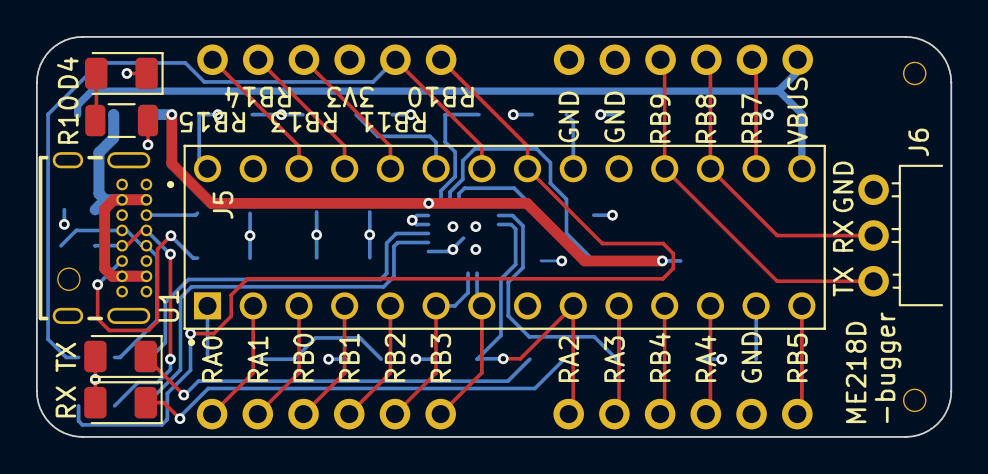
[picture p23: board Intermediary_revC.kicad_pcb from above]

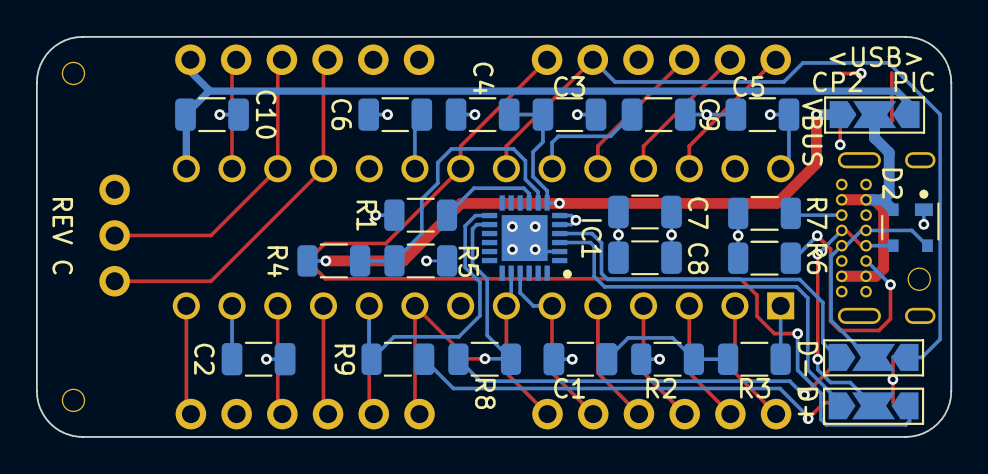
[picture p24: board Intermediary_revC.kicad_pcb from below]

Board: 4 copper layers, 50.8 x 22.2 mm, 38 parts (27 on the bottom side), 38 nets.

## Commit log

2023-01-13 Add git ignore with recommended KiCAD settings
2023-01-13 Add design and fab files for intermediary revC and enclosure
    [114-87-328-41-134161.SLDASM, COMPOUND_2.SLDPRT, CP2102N-A02-GQFN24.SLDASM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]
2023-01-13 Write fab and assembly section of readme and modify gitignore to allow csv
    [Intermediary_revC_jlc.csv, Intermediary_revC_jlc_bottom.csv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]
2023-01-22 Add soldering images
2023-01-22 Add soldering images to readme
